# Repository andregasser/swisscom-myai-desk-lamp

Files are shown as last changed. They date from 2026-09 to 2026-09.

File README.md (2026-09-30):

# myAI Cube

Eine kleine Würfellampe zum Selberdrucken: weißes PLA, sanftes Licht und das myAI-Logo mittig auf allen vier Seiten. Entwickelt für den **Bambu Lab P1S** und das **LED Lamp Kit 001 / MH001**.

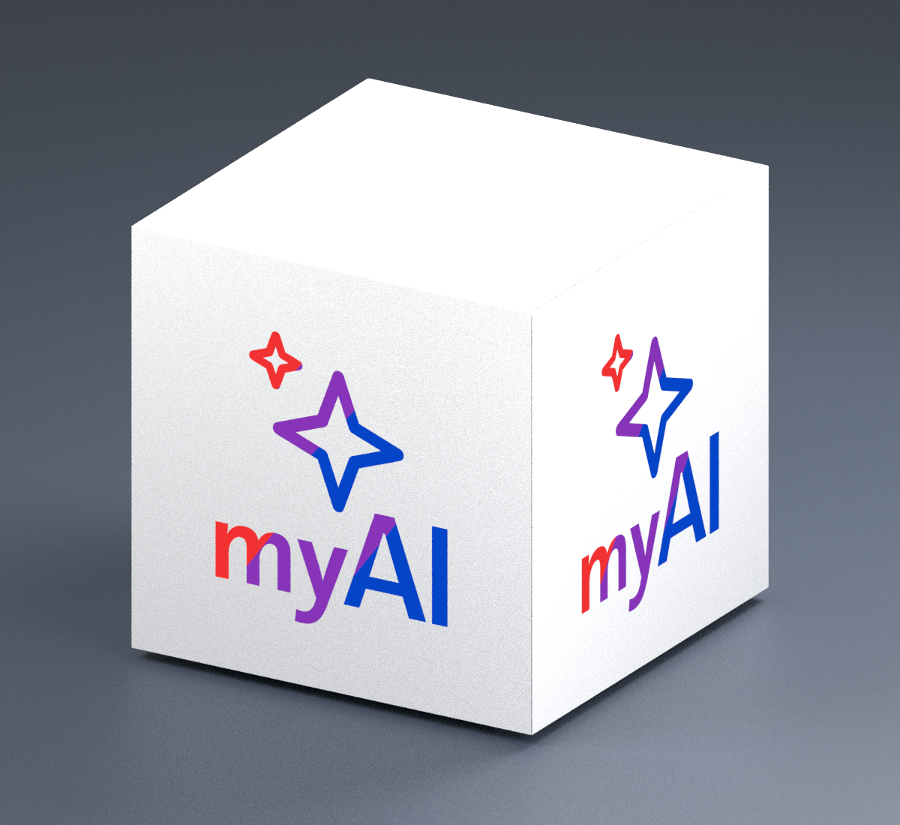
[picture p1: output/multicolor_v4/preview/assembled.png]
myAI Cube v4: durchgehend plane Seiten mit integrierten farbigen Logos


*Technische Farbansicht der CAD-Geometrie: Die Logos zeigen die nominellen sRGB-Farben ohne Aufhellung durch Beleuchtung. Keine Vorhersage realer Filamentfarben oder Lichtwirkung.*

## Die Idee

Ein **15 × 15 × 15 cm** großer Würfel mit **0,8 mm dünnen Leuchtflächen**, integrierten Logos, Boden mit LED-Aufnahme und abnehmbarem Deckel. Für das Logo gibt es eine farbige AMS-Variante und eine einfarbige Alternative.

## Plane Seiten mit AMS — v4

**Vier vollflächige Seitenplatten, außen ohne Vertiefungen oder vorstehende Rahmen.** Die Befestigung liegt innen; nur schmale Montagefugen bleiben an den Würfelkanten. Die 0,8-mm-Leuchtflächen und Logos sind bündig. Innenliegende Führungsleisten erlauben das Einschieben von oben.

**Für ein AMS mit vier Farben:** Weiß, Blau, Violett und Rot. Sterne und Schriftzug „myAI“ folgen Rot → Violett → Blau als feste Farbstufen. Sechs Farbwechsel pro Platte. [Farbvergleich mit den Original-SVGs](output/multicolor_v4/preview/color_reference.png).

Luft und Kabel führen unter dem Boden hindurch. Vier 4-mm-Druckfüße schaffen Abstand; die Gesamthöhe bleibt **150 mm einschließlich Füßen**. Die obere Entlüftung liegt in der 0,8-mm-Deckelfuge auf der Oberseite. Die Füße werden eingesteckt und angeklebt; die Seitenplatten kommen ohne Klebstoff aus.

[Druckdateien & Montage v4](docs/MEHRFARBIG_V4.md) · [Farbprobe](output/multicolor_v4/print/01_color_test_P1S.3mf) · [Führungs-Passprobe](output/multicolor_v4/print/07_fit_P1S.3mf) · [Komplettpaket v4](output/myAI_Cube_150_P1S_AMS_v4.zip)

Sieben vorbereitete P1S-Projekte, keine Stützen. Lampe ohne Proben laut Slicer etwa **267 g PLA und 17 h 22 min**. Zuerst die neue Führung mit der Passprobe prüfen. [Frühere AMS-Variante v3](docs/MEHRFARBIG_V3.md).

**Stand: Prototyp.** Digital geprüft und geslict. Physischer Probedruck und Temperaturtest stehen noch aus.

## Einfarbige Variante v2 drucken

Die ursprüngliche Variante besteht aus Körper, Boden und Deckel. Das innen verstärkte Logo soll sich im Licht dunkler abzeichnen; kein AMS erforderlich. Diese Variante besitzt noch sichtbare Lüftungsöffnungen.

Die 3MF-Projekte sind ausgerichtet und für **P1S · 0,4-mm-Düse · weißes PLA · strukturierte PEI-Platte** vorbereitet. In Bambu Studio **als Projekt** öffnen, eigenes Filament und Druckplatte prüfen und bei Änderungen neu slicen.

| Zuerst testen | Danach die Lampe drucken |
|---|---|
| [Testplatte: Licht und Passung](output/print/01_tests_P1S.3mf) | [Körper](output/print/02_body_P1S.3mf) · [Boden](output/print/03_base_P1S.3mf) · [Deckel](output/print/04_lid_P1S.3mf) |

**Druckprofil:** 0,20-mm-Schichten, keine Stützen. Die Hauptteile benötigen laut Slicer etwa **238 g PLA und 15 h 42 min**. LED-Kit und eine passende 5-V-USB-Stromversorgung kommen dazu.

**Stand: Prototyp v2.** Geometrie und Slicing sind geprüft; ein physischer Probedruck steht noch aus. Deshalb zuerst Lichtdurchlässigkeit und Passung mit der Testplatte prüfen.

## Weiterbauen

- [Druck & Montage](docs/DRUCK_UND_MONTAGE.md) — vom Probedruck zur fertigen Lampe.
- [Projektdetails](docs/PROJEKTDETAILS.md) — Maße, Druckzeiten, Aufbau und Quellen.
- [CAD & Validierung](docs/CAD_UND_VALIDIERUNG.md) — Konstruktion reproduzieren und prüfen.
- [STL-Dateien](output/stl) · [CAD-Parameter](cad/parameters.json) · [Generator](cad/build.py) — für eigene Anpassungen.

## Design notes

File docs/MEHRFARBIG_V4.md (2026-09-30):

# myAI Cube v4 — vier durchgehend plane Seiten

Der Würfel misst **150 × 150 × 150 mm einschließlich Füßen**. Jede Seite besteht aus einer vollflächigen Platte mit bündig integriertem myAI-Logo. Es gibt keine vertieften Logo-Felder, vorstehenden Rahmen oder Deckelblenden an den Seiten. Die Befestigung liegt innen.

V4 mit durchgehend planen Seitenflächen

*Technische Farbansicht der CAD-Geometrie. Logo-Farben werden als nominelle sRGB-Werte dargestellt; keine Vorhersage realer Filamentfarben oder Leuchtwirkung.*

## Aufbau und Oberfläche

- Vier identische Platten: **149,6 × 146 mm**, Leuchtfläche **0,8 mm** stark. Die 0,4-mm-Farbeinlagen liegen bündig in der Vorderseite, dahinter bleiben 0,4 mm Weiß. Die schmalen inneren Führungsleisten erhöhen die lokale Druckhöhe auf 2,8 mm.
- Die Außenflächen liegen auf den Würfelebenen x/y = 0 und 150 mm. Die vertikalen Plattenkanten sind innen auf Gehrung geschnitten, mit 0,2 mm Abstand zur theoretischen Würfelkante. Es bleiben schmale Montagefugen an den vier Kanten; keine eingefassten Felder auf den Seiten.
- Zwei innenliegende, schwalbenschwanzförmige Leisten je Platte gleiten von oben in passende Nuten des inneren Rahmens. Nominell 0,2 mm Spiel um das Führungsprofil; der untere Anschlag trägt die Platte. Der Deckel begrenzt das Anheben. Die Platten werden nicht angeklebt.
- Die Logo-Kontur bleibt auf allen vier montierten Seiten bei **75 / 75 mm** zentriert. Rahmen, Boden und Deckel liegen hinter den Außenflächen.

Die Sichtseite liegt beim Druck auf dem Bett und übernimmt dessen Oberflächenstruktur. „Plan“ bezeichnet hier die Geometrie ohne Absatz; die vorbereitete strukturierte PEI-Platte erzeugt keine polierte Oberfläche. Die Ebenheit großer, dünner PLA-Platten und der Einfluss der inneren Leisten auf die Lichtwirkung müssen am Druck geprüft werden.

## Vier AMS-Farben

| Projekt-Filament | PLA-Farbe | Vorschauwert |
|---|---|---|
| 1 | Weiß | `#FFFFFF` |
| 2 | Blau | `#0445C8` |
| 3 | Violett | `#8734B8` |
| 4 | Rot | `#F23232` |

Sterne und Schrift folgen **Rot → Violett → Blau**. Konturen und Verlaufsrichtungen stammen aus der unveränderten dunklen Original-SVG. Die Farben bleiben gegenüber v3.2.1 erhalten: Rot und Blau sind originale Farbstopps, Violett ist eine gewählte Zwischenfarbe. Das AMS druckt klar getrennte Farbstufen, keinen stufenlosen Verlauf. Eine winzige separate Kontur unterhalb der Düsenauflösung entfällt.

[Direkter Vergleich mit beiden Original-SVGs](../output/multicolor_v4/preview/color_reference.png). Die Druckpalette bildet die zusätzlichen hellblauen/cyanfarbenen Zwischenstufen des Originals nicht exakt ab. Die reale Farbe bestimmt die eingelegte Spule.

## Druckdateien

**[Komplettes Druck- und Quellenpaket v4](../output/myAI_Cube_150_P1S_AMS_v4.zip)**. Im Paket die aktuellen Projekte unter `output/multicolor_v4/print/` verwenden; ältere Varianten liegen separat bei.

Alle Projekte sind für **P1S · 0,4-mm-Düse · PLA · 0,20-mm-Schichten · strukturierte PEI-Platte** ausgerichtet und geslict. Als Projekt in Bambu Studio öffnen und die Projekt-Filamente beim Senden den richtigen AMS-Fächern zuordnen. Bei Änderungen an Filament oder Druckplatte neu slicen. Voreinstellung: Generic PLA, 220 °C Düse und 55 °C Bett.

| Druckprojekt | Anzahl | Zeit je Druck | PLA je Druck¹ |
|---|---:|---:|---:|
| [Farb- und Lichtprobe](../output/multicolor_v4/print/01_color_test_P1S.3mf) | zuerst 1 | 36 min | 7,44 g |
| [Passprobe der inneren Führung](../output/multicolor_v4/print/07_fit_P1S.3mf) | zuerst 1 | 23 min | 2,18 g |
| [Vollflächige Seitenplatte](../output/multicolor_v4/print/02_panel_P1S.3mf) | 4 | 1 h 49 min | 28,34 g |
| [Innerer Rahmen](../output/multicolor_v4/print/03_frame_P1S.3mf) | 1 | 4 h 42 min | 53,70 g |
| [Boden mit LED-Aufnahme](../output/multicolor_v4/print/04_base_P1S.3mf) | 1 | 3 h 38 min | 74,32 g |
| [Deckel](../output/multicolor_v4/print/05_lid_P1S.3mf) | 1 | 1 h 24 min | 22,42 g |
| [Vier Füße auf einer Platte](../output/multicolor_v4/print/06_feet_P1S.3mf) | 1 Satz | 20 min | 3,41 g |

¹ Einschließlich Brim, Spülmaterial und Reinigungsturm, soweit vom Slicer erfasst. Lampe ohne Proben etwa **267 g PLA und 17 h 22 min**. Keine Stützen. Jedes Paneel benötigt sechs Farbwechsel.

1. Zuerst Farbprobe und Passprobe drucken. Die Farbprobe besitzt denselben 0,4 + 0,4-mm-Schichtaufbau, verkleinertes Logo und keine Führungsleisten. Sie beurteilt Farben und Licht, keine Details in Originalgröße.
2. Die Passprobe besteht aus einem 20 mm hohen Ausschnitt des echten Eckpfostens und einem passenden Plattenstreifen mit Führungsleiste, jeweils in der späteren Druckorientierung. Den Streifen aufrichten und die Leiste von oben in eine der beiden Nuten schieben. Die Verbindung soll gleiten, ohne Gewalt oder Aufspreizen des Pfostens. Diese Probe prüft den Querschnitt, noch nicht den Verzug über die volle Führungslänge.
3. Danach zunächst einen Rahmen und eine vollständige Seitenplatte drucken und montieren. Erst nach erfolgreicher Passprobe die übrigen drei Platten drucken. Dünne Platten vom abgekühlten Bett lösen; Brim und lose Fäden sorgfältig entfernen.
4. Die Logo-Vorderseite ist die Bettseite. **Nicht zusätzlich spiegeln oder wenden.** Die vier Farbvolumen bleiben Teile eines gemeinsamen Objekts. Die breitere Platte ist auf dem Bett seitlich versetzt, damit Brim und Reinigungsturm ausreichend Abstand haben.

Der Reinigungsturm ist aktiviert; Fremdfarben werden nicht in die weiße Rückschicht gespült. Vorgesehene Spülmengen: 650 mm³ beim Wechsel auf Weiß, 450 mm³ bei anderen Farbwechseln, anhand des eigenen Filaments prüfen. In den ersten zwei Schichten liegen alle vier Farben, darüber ausschließlich Weiß einschließlich der Führungsleisten. Die CLI-Dateien enthalten Geometrie und G-Code, aber keine integrierten Vorschaubilder.

## Montage und Belüftung

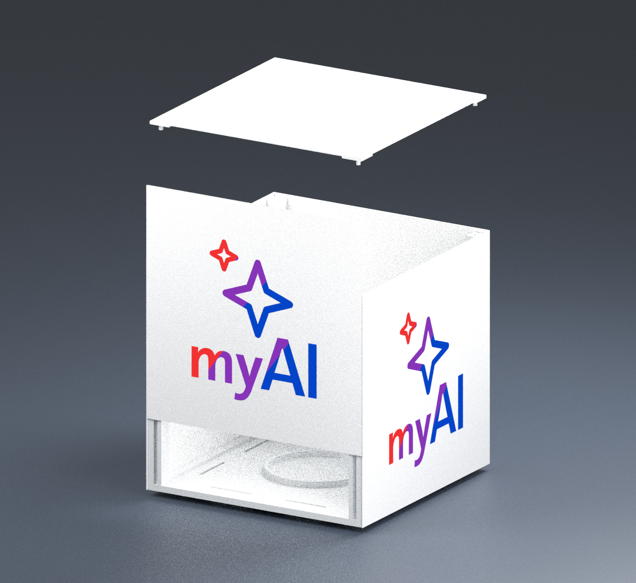
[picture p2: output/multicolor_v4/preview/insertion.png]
Deckel abgenommen und vordere Seitenplatte angehoben


1. Vier Füße in die Aufnahmen auf der Bodenunterseite stecken und mit wenig PLA-geeignetem Klebstoff fixieren. Die 4-mm-Pads flach anlegen. Zapfen Ø 4,0 × 1,8 mm, Aufnahmen Ø 4,4 × 2,0 mm: bewusst eine lose Passung.
2. LED Lamp Kit 001/MH001 in die nominell 60-mm-Aufnahme setzen und mit dem Kit-Klebepad befestigen. Die Konstruktion verwendet ein nominell 59-mm-Modul; das konkrete Kit prüfen. Seine Auflage liegt 7 mm über der Stellfläche.
3. Kabel durch den nach hinten offenen, 6 mm breiten Bodenschlitz nach unten legen. Es verlässt die Lampe **unter** der hinteren Seitenplatte. Die Füße schaffen dafür 4 mm Bodenfreiheit. Den tatsächlichen Kabeldurchmesser und einen knickfreien Verlauf prüfen; kein Stecker muss durch eine geschlossene Bohrung gefädelt werden.
4. Rahmen auf die vier Führungsstifte des Bodens setzen. Vier Seitenplatten mit aufrechter Schrift und Bettseite nach außen von oben einschieben, bis die inneren Leisten auf den Anschlägen sitzen. Der Rahmen darf nicht gewaltsam gespreizt werden.
5. Deckel in die vier oberen Aufnahmen setzen. Zum Öffnen an der oberen Deckelfuge vorsichtig abheben. Boden und Deckel stecken lose; beim Tragen den Boden unterstützen.

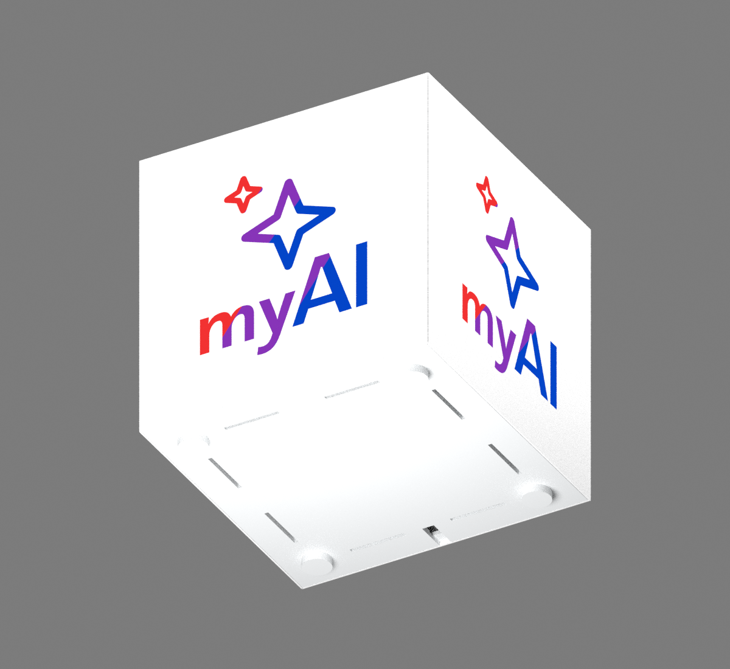
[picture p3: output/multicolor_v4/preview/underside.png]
Unterseite mit Einlässen, Füßen und Kabelschlitz


Die Belüftung ist an die planen Seiten angepasst:

- **Einlass unten:** Acht Bodenschlitze à 28 × 2 mm, zusammen nominell 448 mm². Auf einer harten, ebenen Fläche bleiben sie durch die 4-mm-Füße offen.
- **Auslass oben:** Vier unterseitige Deckelkanäle à 120 × 1,2 mm führen in die **0,8 mm breite Montagefuge zwischen Deckel und Seitenplatten auf der Oberseite**. Dort beträgt der nominelle Austrittsquerschnitt über den vier Kanalabschnitten 384 mm². Diese schmale obere Fuge bleibt sichtbar und offen; die eigentliche Deckelfläche ist geschlossen. Es gibt keine vertieften Auslässe auf den Seiten.

Die Luftwege sind im montierten CAD frei und zusammenhängend. Das ist kein Nachweis ausreichender Kühlung. Temperatur an LED-Aufnahme, Boden und Deckel im beaufsichtigten Betrieb bis zum stabilen Zustand prüfen. Passung, Verzug, Lichtverteilung und Dauerbetrieb sind noch nicht physisch bestätigt.

**V4 als vollständigen neuen Teilesatz verwenden.** Die früheren Paneele, Rahmen, Böden, Deckel und Füße sind hierfür nicht vorgesehen. Die alten v3-Dateien und Versionspakete bleiben im Repository erhalten.

## Reproduzieren und prüfen

Quellen: [AMS-Parameter](../cad/multicolor_parameters.json), [Generator](../cad/build_multicolor.py). Grundfunktionen und LED-Ring werden aus `cad/build.py` importiert. `output_folder` wählt das aktuelle Ausgabeverzeichnis. Allgemeine Umgebung: [CAD & Validierung](CAD_UND_VALIDIERUNG.md).

```sh
.venv/bin/python cad/build_multicolor.py
.venv/bin/python scripts/prepare_profiles.py /pfad/zu/BambuStudio/resources/profiles/BBL
.venv/bin/python scripts/slice_multicolor.py /pfad/zu/bambu-studio
.venv/bin/python scripts/validate_multicolor.py
blender -b -t 4 --python scripts/render_multicolor.py
.venv/bin/python scripts/render_color_reference.py
.venv/bin/python scripts/validate_colors.py
.venv/bin/python scripts/package.py
```

Verwendeter Slicer: Bambu Studio 2.8.2.61. Die Prüfungen stehen in [Geometrie](../output/multicolor_v4/geometry_validation.json), [Druckdateien](../output/multicolor_v4/print_validation.json) und [Farben](../output/multicolor_v4/color_validation.json):

- Geschlossene Materialvolumen, vollständige Abdeckung der Platte einschließlich Leisten, keine relevanten Materialüberschneidungen, kollisionsfreie Montage und Einschubbewegung. Seitliches Herausziehen wird durch die Führungsgeometrie blockiert.
- Außenmaß 150³ mm, Logo-Zentrierung 75/75 mm und durchgehende ebene Außenhaut auf allen vier Seiten, mit Ausnahme der vorgesehenen schmalen Kantenfugen. Freie Luft- und Kabelwege. Die Boolesche Volumentoleranz beträgt 0,001 mm³.
- Sieben geslicte P1S-Projekte, korrekte AMS-Zuordnung, gültige G-Code-Prüfsummen, Bettgrenzen einschließlich Brim/Reinigungsturm, keine Stützen oder Slicer-Druckwarnungen.
- Nominelle RGB-Farben in den technischen Vorschauen; kein gemessener Farb- oder Helligkeitsnachweis am gedruckten Material.

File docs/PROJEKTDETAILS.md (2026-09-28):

# Projektdetails — myAI Cube

3D-druckbare Würfellampe aus weißem PLA für das **Bambu Lab LED Lamp Kit 001 / MH001 (nominal Ø 59 mm)**. Vier gleiche Logo-Seiten, separate Bodenplatte, abnehmbarer Deckel. Zusammengesetzt **150 × 150 × 150 mm**.

**Version 2:** Die tatsächliche Logo-Kontur ist auf jeder montierten 150-mm-Seite geometrisch zentriert (Mitte bei 75 / 75 mm). Die Zentrierung berücksichtigt die leeren SVG-Ränder, Boden-/Deckelhöhe und die Neigung des inneren Reliefs. Das Logo bleibt ein integrierter Teil des weißen Drucks.

## Direkt zum Druck

Die fertig ausgerichteten, mit **Bambu Studio 2.8.2.61** geslicten P1S-Projekte liegen in [output/print](../output/print). Jede Datei enthält eine Druckplatte, das Modell, die Einstellungen und den erzeugten G-Code.

| Reihenfolge | Projekt | Inhalt | PLA, ca. | Zeit, ca. |
|---|---|---|---:|---:|
| 1 | [01_tests_P1S.3mf](../output/print/01_tests_P1S.3mf) | Vier Lichtproben, LED-Passring, zwei Steckproben | 28 g | 1 h 56 min |
| 2 | [02_body_P1S.3mf](../output/print/02_body_P1S.3mf) | Vierseitiger Lampenkörper, 145 mm hoch | 116 g | 9 h 19 min |
| 3 | [03_base_P1S.3mf](../output/print/03_base_P1S.3mf) | Boden, 3 mm plus innenliegende Aufnahmen | 89 g | 4 h 14 min |
| 4 | [04_lid_P1S.3mf](../output/print/04_lid_P1S.3mf) | Deckel, außen bündig; Führung innen | 34 g | 2 h 9 min |

**Profil:** P1S, 0,4-mm-Düse, weißes Generic PLA, strukturierte PEI-Platte, 0,20-mm-Schichten, Arachne, zwei Wände, 100 % Füllung, keine Stützen, 4-mm-Außenbrim. Das eingebettete Filamentprofil verwendet 220 °C Düse und 55 °C Bett. Keine AMS-Farbwechsel.

1. `01_tests_P1S.3mf` in Bambu Studio **als Projekt** öffnen und im Maßstab 100 % belassen.
2. P1S mit 0,4-mm-Düse, die tatsächlich verwendete Druckplatte und dein weißes PLA auswählen. Wenn du ein anderes Filament- oder Plattenprofil verwendest, erneut slicen. Die Ausrichtung beibehalten.
3. Testplatte drucken. [Passung und Licht prüfen](DRUCK_UND_MONTAGE.md), danach die drei Hauptplatten drucken.

Die Lampe selbst benötigt etwa **238 g PLA / 15 h 42 min**. Die Angaben sind Slicer-Schätzungen inklusive Brim; tatsächliche Werte können abweichen. Die Konstruktion wurde digital geprüft und geslict, **noch nicht physisch probegedruckt**.

## Konstruktion

- Leuchtflächen und Deckelmitte: 0,8 mm. Randbereiche: 3 mm am Körper, 2 mm am Deckel. Verstärkte Ecken.
- Vollständiges gestapeltes myAI-Logo auf allen vier Seiten. Einfarbiges Relief **innen**, außen ebene Flächen. Das Logo ist mit insgesamt etwa 1,6 mm Material dicker und soll bei Beleuchtung dunkler erscheinen; Farbverläufe sind nicht Bestandteil des Drucks.
- LED-Aufnahme: Ø 60,0 mm innen, 4 mm hoch, mit Kabelschlitz. Die mitgelieferte Ø-40-mm-Klebescheibe fixiert das Kit am Boden. Die Führung ist keine Klemm- oder Schraubverbindung.
- 0,35 mm Spiel je Seite an den Führungsleisten. Körper und Deckel sitzen lose auf; sie sind abnehmbar und verriegeln nicht.
- Kabelauslass hinten, unten offen, 6 mm breit. Vier kleine Lüftungsöffnungen pro Seitenwand und vier Schlitze im Deckel.

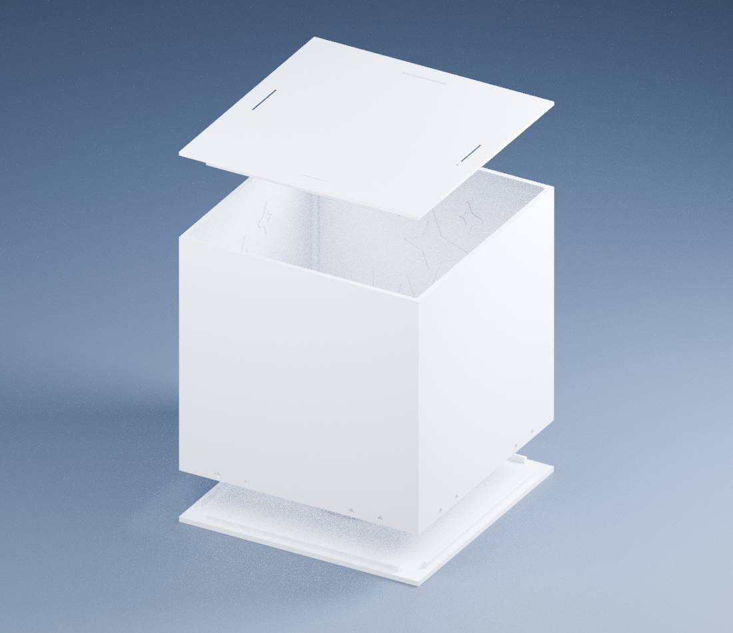
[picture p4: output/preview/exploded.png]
Montageansicht


Ansicht aus den tatsächlichen Druckmeshes. Die zusätzliche [Beleuchtungsansicht](../output/preview/assembled.png) ist eine schematische Materialsimulation, keine Vorhersage der Helligkeit oder des Logokontrasts.

## Dateien und Änderungen

- [STL-Einzelteile](../output/stl): Millimeter, bereits in Druckorientierung.
- [CAD-Parameter](../cad/parameters.json) und [Generator](../cad/build.py): reproduzierbare Geometrie.
- [Druck- und Montageanleitung](DRUCK_UND_MONTAGE.md).
- [Geometrieprüfung](../output/validation.json) und [Druckdateiprüfung](../output/print_validation.json).
- [Original-Logos](../assets/logos): unverändert. Für den Druck wird die Kontur der Light-Variante benutzt; ein winziges, nicht druckbares SVG-Dreiecksfragment wird beim Ableiten entfernt.

```sh
python3 -m venv .venv
.venv/bin/pip install -r cad/requirements.txt
.venv/bin/python cad/build.py
```

Nach Parameteränderungen sind die vorhandenen P1S-Druckprojekte veraltet: die neuen Geometrie-3MFs in `output/3mf` erneut slicen. Die Geometrieprüfungen laufen beim Erzeugen automatisch. Für die CLI-Reproduktion siehe [CAD und Validierung](CAD_UND_VALIDIERUNG.md).

## Quellen

- [Bambu LED Lamp Kit 001: Herstellerdaten](https://asia.store.bambulab.com/products/led-lamp-kit-001?modelId=126239&skr=yes): nominal Ø 59 mm, USB 5 V, 3 W. Die Aufnahme hält nur den unteren Rand; sie setzt keine bestimmte Gesamthöhe des Kits voraus.
- [Bambu 3D Printing Night Light Design Guidelines, PDF-Spiegel](https://www.eel3dshop.com/shop_ordered/54291/pic/Datasheet/BambuLab/LED_Lamp_Kit-001_Design_Guide.pdf): 0,8-mm-Lampenschirm und Belüftung als Konstruktionsgrundlage.
- [Bambu Studio 2.8.2.61](https://github.com/bambulab/BambuStudio/releases/tag/v02.08.02.61): offizieller Slicer und mitgelieferte P1S-/PLA-Profile.

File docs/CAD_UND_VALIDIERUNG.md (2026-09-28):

# Reproduzierbarkeit und Prüfstand

## Geometrie

`cad/build.py` erzeugt die Geometrie mit Manifold3D. Die SVG-Kontur wird aus dem unveränderten Light-Logo abgeleitet und als Relief mit der Wand vereinigt. Kurven werden mit höchstens etwa 0,2 mm Abtastabstand polygonisiert. Das separate Dreiecksfragment am A mit weniger als 0,02 mm² wird beim Ableiten ausgelassen, um einen nicht druckbaren Punktkontakt zu vermeiden.

Das Logo wird nach innen und gleichzeitig nach oben extrudiert. Die dadurch geneigten Unterkanten reduzieren freie Überhänge beim aufrechten Druck. Die äußeren Seitenflächen bleiben eben. Die Farbdaten beider Original-SVGs bleiben in `assets/logos` erhalten, werden aber nicht als Druckfarben übernommen.

Ab Version 2 wird die Begrenzungsbox der zusätzlichen Logo-Materialstärke auf die Mitte der zusammengesetzten Seite gesetzt, statt die SVG-Zeichenfläche zu zentrieren. Eine numerische Prüfung bestätigt 75 / 75 mm für die projizierte Kontur. Alle vier Seiten verwenden dieselbe Geometrie, jeweils um 90° gedreht.

Für Änderungen zuerst die Parameter anpassen und dann:

```sh
.venv/bin/python cad/build.py
```

Der Generator prüft geschlossene, zusammenhängende Volumenkörper, positive Volumina, Druckbettkontakt und Teilegrößen. Er prüft die zusammengesetzte Lampe auf paarweise Materialüberschneidungen. Ein nominaler Ø-59-mm-Zylinder als vereinfachter LED-Platzhalter kollidiert nicht mit der Aufnahme. Diese Prüfung ersetzt nicht das reale Kit samt Kabel und Fertigungstoleranzen.

## Bambu Studio

Die mitgelieferten Druckdateien wurden mit **Bambu Studio 02.08.02.61** und dessen offiziellen Ressourcen erzeugt. `scripts/prepare_profiles.py` löst die Vererbung einschließlich der originalen P1S-Start-/End-G-Code-Vorlagen auf. `output/profiles` enthält die konkret verwendeten Profile. Die Druckparameter sind in jedem fertigen 3MF eingebettet.

```sh
.venv/bin/python scripts/prepare_profiles.py /pfad/zu/BambuStudio/resources/profiles/BBL
.venv/bin/python scripts/slice.py /pfad/zu/bambu-studio
.venv/bin/python scripts/validate_prints.py
```

Die Linux-AppImage wurde für die Erstellung nur unter `/tmp` entpackt. Fehlende Laufzeitbibliotheken wurden ebenfalls dort bereitgestellt; sie gehören nicht zum Druckpaket. Zum Öffnen und Drucken genügt eine reguläre Bambu-Studio-Installation, empfohlen 2.8.2 oder neuer.

## Tatsächlich geprüft

- Alle zehn STL-Einzelteile erneut eingelesen: geschlossene, konsistent orientierte, zusammenhängende Körper.
- Zusammengebautes Außenmaß: 150 × 150 × 150 mm. Keine Überschneidung von Boden, Körper und Deckel.
- Vier Platten erfolgreich geslict; in den Slicer-Ergebnisdaten keine Druckwarnungen.
- Eingebettetes Profil: P1S / 0,4 mm / PLA / strukturierte PEI-Platte / 0,20 mm / keine Stützen.
- Die erzeugten Modell- und Brim-Extrusionskoordinaten liegen auf dem nutzbaren Bett und außerhalb des vorderen linken Ausschlussbereichs. Offizielle Start-/Reinigungsbewegungen werden davon getrennt behandelt.
- ZIP-Integrität der 3MFs und eingebettete MD5-Prüfsumme jedes G-Codes geprüft. SHA-256-Prüfsummen stehen in `output/print_validation.json`.

Die CLI kann in dieser Umgebung keine OpenGL-Plattenvorschaubilder erzeugen; sie meldet dafür einen Display-Fehler, exportiert aber erfolgreich Geometrie, Profile und geslicten G-Code. Die Projekte enthalten deshalb keine eingebetteten Platten-Thumbnails. Bambu Studio kann die Modelle beim Öffnen selbst anzeigen. Separate Modellansichten liegen unter `output/preview`.

**Nicht physisch geprüft:** Sitz am konkreten LED-Kit, Drucktoleranzen, Verzug, langfristige Wärmebeständigkeit, Leuchtdichte und Logo-Kontrast. Dafür liegt die Testplatte bei. Die Renderansichten zeigen die Geometrie; Material und Beleuchtung sind illustrativ.

## Vorschauen

`output/preview/assembly.glb` enthält die tatsächlichen drei montierten Druckmeshes und ist nicht als Druckplatte gedacht. `scripts/render.py` erzeugt mit Blender 5 die PNG-Ansichten aus den STL-Dateien:

```sh
blender -b -t 4 --python scripts/render.py
```

Die originalen P1S-/PLA-Grundprofile stammen aus [Bambu Studio](https://github.com/bambulab/BambuStudio/tree/v02.08.02.61/resources/profiles/BBL). Die Befehlszeile folgt der [offiziellen CLI-Dokumentation](https://github.com/bambulab/BambuStudio/wiki/Command-Line-Usage).

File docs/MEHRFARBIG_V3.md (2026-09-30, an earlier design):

# myAI Cube v3.2.1 — Logo direkt mit dem AMS drucken

> Archivierter Entwurf mit zurückgesetzten Seitenfeldern. Der aktuelle Entwurf mit planen Seiten ist [v4](MEHRFARBIG_V4.md). Die folgenden Reproduktionsbefehle gelten für die Quellen im v3.2.1-Archiv; die aktuellen Quellen im Repository erzeugen v4.

Der Würfel bleibt **150 × 150 × 150 mm einschließlich Füßen** groß. Vier identische, flach gedruckte Leuchtpaneele werden von oben in einen weißen Rahmen eingeschoben. Das mehrfarbige Logo ist bündig in jedes Paneel integriert. Der abnehmbare Deckel schließt die Führungen. Die Logos benötigen keinen Klebstoff.

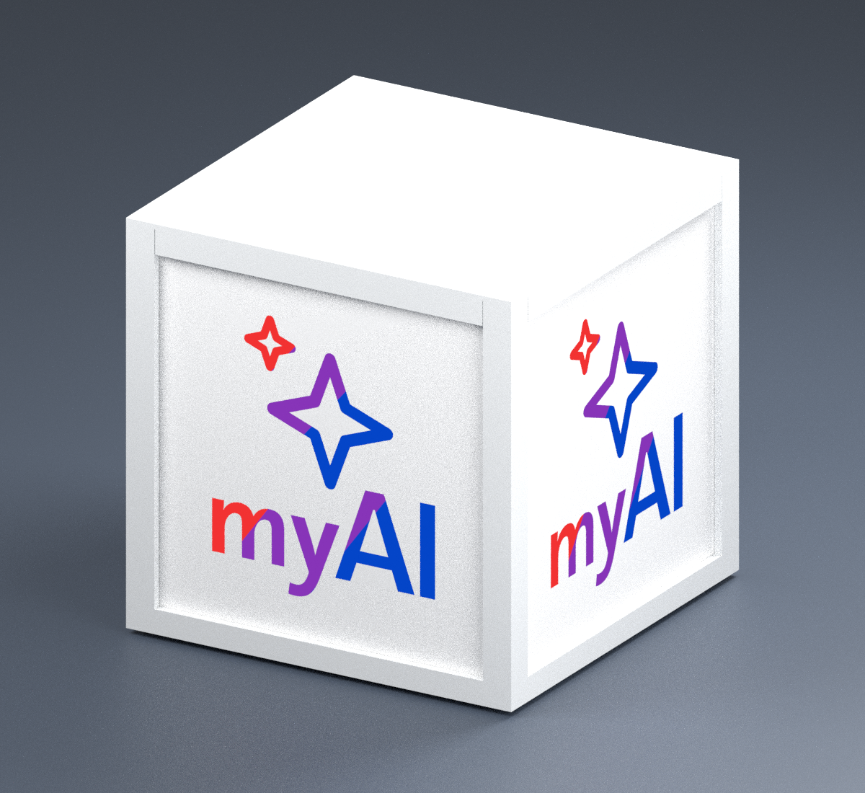
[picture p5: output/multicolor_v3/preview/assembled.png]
Zusammengesetzter AMS-Entwurf


*Technische Farbansicht der tatsächlichen CAD-Geometrie. Die Logo-Flächen zeigen nominelle sRGB-Farben ohne Aufhellung durch Szenenbeleuchtung. Keine Vorhersage der Leuchtwirkung oder realer Filamentfarben.*

## Vier Farben in einem AMS

| Projekt-Filament | PLA-Farbe | Verwendung |
|---|---|---|
| 1 | Weiß | Paneel, Rückschicht, Rahmen, Boden, Deckel, Füße |
| 2 | Blau | Blaue Bereiche in Sternen und Schrift |
| 3 | Violett | Mittlere Farbstufe in Sternen und Schrift |
| 4 | Rot | Rote Bereiche in Sternen und Schrift |

Die Konturen stammen jetzt aus der unveränderten **dunklen Logo-SVG**: Sie enthält Farbverläufe sowohl in den Sternen als auch in „myAI“. Die zuvor verwendete helle SVG besitzt einfarbig dunkelblaue Schrift. Beide Originaldateien bleiben unverändert.

Die gewünschte Druckfolge ist **Rot → Violett → Blau**. Sterne und Schrift behalten ihre jeweils eigene Verlaufsrichtung aus der SVG; der Generator liest die Gradientenzuordnung jedes Pfads. Die Farbpalette wird für diesen Entwurf bewusst angepasst: Weiß `#FFFFFF`, Blau `#0445C8`, Violett `#8734B8`, Rot `#F23232`. Die Original-SVG enthält zusätzlich hellblaue/cyanfarbene Zwischenstufen, die hier durch die gewünschte dreistufige Folge ersetzt werden. Die Hexwerte dienen der Vorschau und sind keine gemessenen Filamentfarben.

Es ist eine **druckbare Vierfarben-Annäherung mit sichtbaren Farbkanten**, kein stufenloser Verlauf. Entlang jedes originalen Gradientenvektors wird bis t = 0,18 Rot, von t = 0,18 bis 0,50 Violett und danach Blau verwendet; auch innerhalb einzelner Buchstaben entstehen Farbwechsel. Diese Grenzen stehen in `gradient_band_edges` in den CAD-Parametern. Eine winzige separate Kontur unterhalb der Düsenauflösung entfällt wie bei den bisherigen Versionen.

### Farbvergleich und Vorschaukorrektur v3.2.1

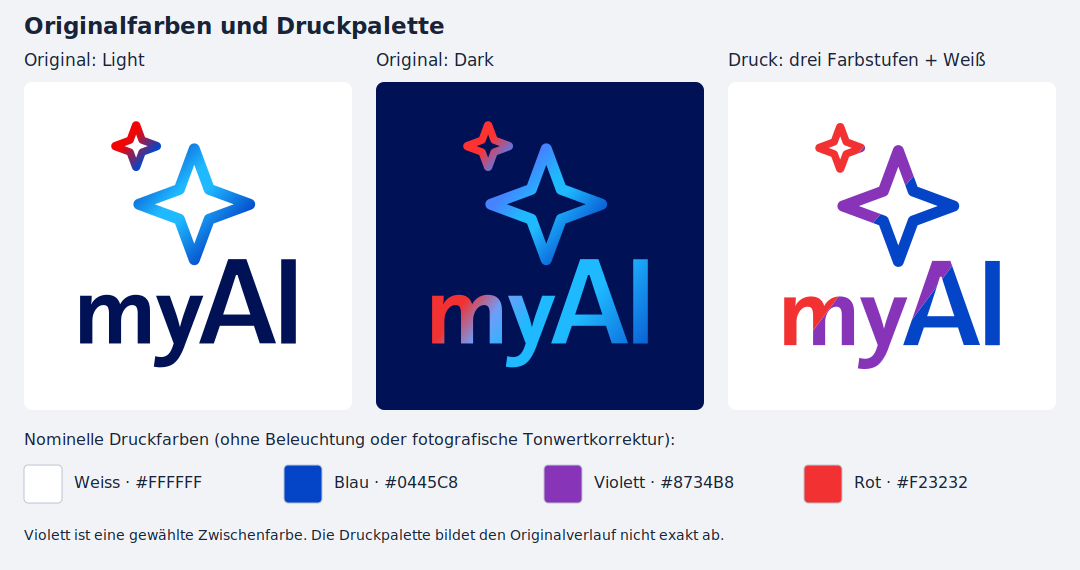
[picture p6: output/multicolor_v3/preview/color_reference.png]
Originale Light/Dark und unbeleuchtete Druckpalette im direkten Vergleich


Die vorherige 3D-Vorschau hellte die Farben durch Beleuchtung und fotografische Tonwertkorrektur stark auf. Rot `#F23232` und Blau `#0445C8` entsprechen bereits Farbstopps der dunklen Original-SVG; diese Werte bleiben erhalten. Violett `#8734B8` ist eine gewählte Zwischenfarbe, kein eigener Farbstopp in der Originaldatei.

Die neue technische Ansicht gibt die Logo-Farben direkt zur Kamera aus, ohne Beleuchtungsaufhellung und mit Standard-sRGB-Ausgabe. Weiße Gehäuseteile bleiben schattiert. Die farbigen Flächen sind dadurch **keine Simulation leuchtenden Filaments**. Der [Farbprüfbericht](../output/multicolor_v3/color_validation.json) prüft die Farbfelder der Vergleichsgrafik und große Innenflächen der gerenderten Logos gegen die CAD-Farbwerte.

**V3.2.1 ändert nur Darstellung, Prüfungen und Dokumentation.** Geometrie, Filamentprofile und geslicte Druckdateien sind identisch zu v3.2; kein erneuter Druck wegen dieser Vorschaukorrektur nötig. Wie dunkel die reale Lampe erscheint, hängt vom tatsächlich eingelegten Filament und der Beleuchtung ab. Hexwerte im Projekt ändern die Farbe einer realen Spule nicht.

Die Paneele sind **133,4 × 139,4 × 0,8 mm** groß. Außen liegen 0,4 mm tiefe Farbeinlagen und weißer Hintergrund, dahinter eine durchgehende 0,4-mm-Schicht aus Weiß. Das Logo ist auf jeder montierten Würfelseite bei **75 / 75 mm** zentriert. Farbflächen dämpfen das Licht anders als weißes PLA; Farbe und Kontrast müssen mit dem eigenen Filament geprüft werden.

## Druckdateien

Alle Links führen zu geslicten **Bambu-Studio-Projekten** für P1S, 0,4-mm-Düse, 0,20-mm-Schichten und strukturierte PEI-Platte. Ein Paneel pro Druckplatte; viermal unverändert drucken.

| Druckprojekt | Anzahl | Slicer-Zeit je Druck | PLA je Druck¹ |
|---|---:|---:|---:|
| [Farb- und Lichtprobe](../output/multicolor_v3/print/01_color_test_P1S.3mf) | zuerst 1 | 34 min | 7,05 g |
| [Seitenpaneel mit Logo](../output/multicolor_v3/print/02_panel_P1S.3mf) | 4 | 91 min | 23,24 g |
| [Rahmen](../output/multicolor_v3/print/03_frame_P1S.3mf) | 1 | 5 h 52 min | 69,56 g |
| [Boden / LED-Aufnahme](../output/multicolor_v3/print/04_base_P1S.3mf) | 1 | 3 h 51 min | 76,27 g |
| [Deckel](../output/multicolor_v3/print/05_lid_P1S.3mf) | 1 | 2 h | 31,66 g |
| [Vier Füße auf einer Platte](../output/multicolor_v3/print/06_feet_P1S.3mf) | 1 Satz | 15 min | 1,90 g |

¹ Einschließlich Brim, Spülmaterial und Reinigungsturm, soweit vom Slicer erfasst. Lampe ohne Testprobe insgesamt etwa **272 g PLA und 18 h 2 min**. Es werden keine Stützen erzeugt. Jedes Paneel benötigt sechs Farbwechsel. Der Boden druckt mit der flachen Unterseite auf dem Bett; lediglich die kleinen, 4,4 mm breiten Fußaufnahmen werden oben überbrückt. Die Füße drucken mit dem runden Pad auf dem Bett und dem Zapfen nach oben.

**[Komplettes Druck- und Quellenpaket v3.2.1 herunterladen](../output/myAI_Cube_150_P1S_AMS_v3_2_1.zip)**. Das Paket enthält zusätzlich die bisherige einfarbige v2; für diesen Entwurf die Dateien unter `output/multicolor_v3/print/` verwenden. Die älteren v3-, v3.1- und v3.2-Pakete bleiben als Archive erhalten.

1. Die Farbprobe **als Projekt** öffnen. Die vier Projekt-Filamente beim Senden den passenden realen AMS-Fächern zuordnen; die Datei kennt deine geladenen Spulen nicht. Für die weißen Druckprojekte Projekt-Filament 1 dem weißen Fach zuweisen.
2. Eigenes PLA und Druckplatte prüfen. Voreinstellung: Generic PLA, 220 °C Düse, 55 °C Bett. Bei Profil- oder Materialänderungen neu slicen und die Vorschau prüfen.
3. Die Logo-Vorderseite liegt auf dem Druckbett. Im Blick von oben erscheint die Rückseite entsprechend gespiegelt. **Nicht zusätzlich spiegeln oder wenden.** Alle vier Farbvolumen bleiben Teile eines gemeinsamen Objekts.
4. Zuerst die kleine Probe drucken und vor dem LED-Kit prüfen. Sie hat denselben Schichtaufbau, aber nur 35 % der Logo-Größe; sie dient dem Farb-/Lichtvergleich, nicht der Beurteilung feiner Details in Originalgröße oder der mechanischen Passung.
5. Danach einen Rahmen und zunächst ein vollständiges Paneel drucken. Brim sauber entfernen und den Sitz prüfen, bevor die drei übrigen Paneele gedruckt werden. Dünne Paneele erst vom abgekühlten Bett lösen und nicht stark knicken.

Der Reinigungsturm ist aktiviert. Spülen in die Leuchtflächen ist deaktiviert, damit Restfarben nicht in der weißen Rückschicht landen. Vorgesehen sind konservative Spülmengen von 650 mm³ beim Wechsel auf Weiß und 450 mm³ bei anderen Farbwechseln; anhand der Probe für das eigene Filament bewerten. Die kleinen Vorschaubilder innerhalb der 3MF-Dateien fehlen wegen des kopflosen CLI-Exports; die Geometrie und der geslicte G-Code sind enthalten.

## Verdeckte Belüftung

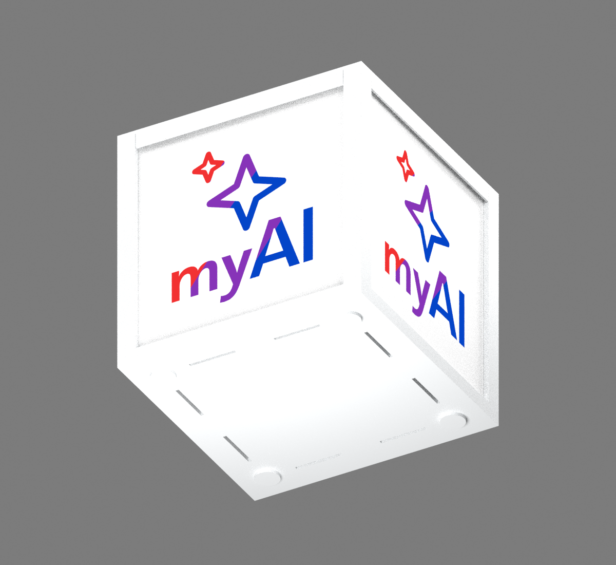
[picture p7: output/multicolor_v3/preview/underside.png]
Unterseite mit acht Lufteinlässen und vier kleinen Füßen


Die Seitenlöcher und die Schlitze auf der Deckelfläche entfallen. Die hintere Kabelöffnung bleibt erhalten.

- **Unten:** Vier separate Druckfüße mit 14 mm Durchmesser schaffen 2 mm Bodenfreiheit. Acht Schlitze à 28 × 2 mm liegen auf der Unterseite. Ihre gesamte nominelle Öffnungsfläche beträgt 448 mm². Der Boden ist nach innen versetzt: Der äußere Auflagerand ist 1 mm stark, die zentrale Platte 3 mm. So bleiben Außenmaße, Paneele und Logo-Position unverändert.
- **Oben:** Vier 100 mm breite und 1,2 mm hohe Kanäle liegen auf der Unterseite des Deckelrandes. Von dort führt die Luft hinter der 1,2 mm starken äußeren Blende nach unten ins Freie. Der Abstand zwischen Blende und Paneel beträgt 2,05 mm. Die Deckelfläche bleibt durchgehend 0,8 mm stark; keine Öffnungen von oben. Die Kanalquerschnitte ergeben zusammen nominell 480 mm².

Das CAD prüft zusammenhängende freie Luftwege vom Raum unter der Lampe bis zum Innenraum und vom Innenraum zu den verdeckten oberen Auslässen. **Das ist keine Strömungs- oder Wärmeberechnung.** Die Umlenkung am Deckel erzeugt einen Strömungswiderstand; die angegebenen Flächen belegen keine ausreichende Kühlleistung. Die Lampe auf eine harte, ebene Fläche stellen, damit die unteren Einlässe frei bleiben.

## Montage

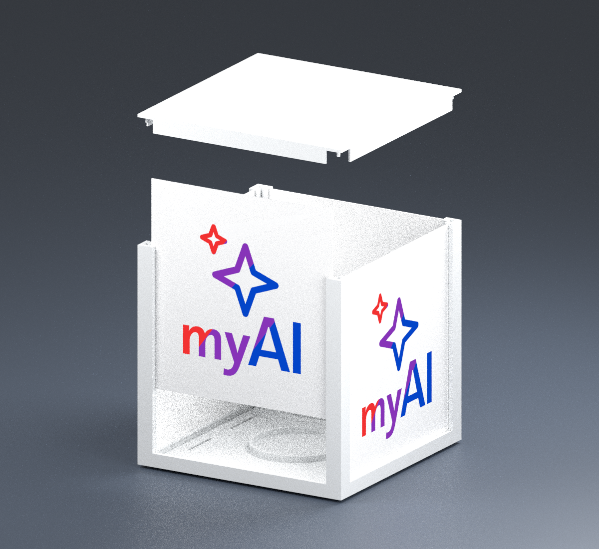
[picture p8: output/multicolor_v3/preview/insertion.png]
Deckel abgenommen, vorderes Paneel teilweise eingeschoben


1. Vier Füße in die runden Aufnahmen auf der Bodenunterseite stecken. Zapfen Ø 4,0 × 1,8 mm, Aufnahme Ø 4,4 × 2,0 mm: bewusst eine lose Passung. Mit wenig PLA-geeignetem Klebstoff fixieren; keine Lüftungsschlitze verschließen. Die 2 mm hohen Pads müssen flach anliegen. Für diesen Schritt ist zusätzlicher Klebstoff erforderlich.
2. LED Lamp Kit 001/MH001 in die nominell 60-mm-Aufnahme des Bodens setzen und mit dem vorgesehenen Klebepad befestigen. Die Auslegung basiert auf einem nominell 59-mm-Modul; tatsächliches Kit vor Montage prüfen. Die LED-Auflage liegt jetzt 5 mm über der Stellfläche. Kabel durch die offene Aussparung führen und den Verlauf zur hinteren Öffnung prüfen.
3. Rahmen auf den Boden setzen, die hintere Kabelöffnung ausrichten. Die Verbindung steckt lose auf dem Boden; kein verriegelter Transportgriff.
4. Vier Paneele von oben in die Führungen schieben, bedruckte Bettseite nach außen und Schrift aufrecht. Seitlich sind nominal 0,3 mm Spiel je Kante vorgesehen; durch die Dicke ergibt sich 0,25 mm vorne und 0,35 mm hinten. Paneele nicht gewaltsam einschieben.
5. Deckel aufsetzen. Seine seitlichen Blenden schließen die oberen Fenster und halten die Paneele in den Führungen. Den Luftspalt hinter der Blende frei lassen. Beim Tragen den Boden unterstützen.

**Rahmen, Boden, Deckel und Füße aus v3.1 passen unverändert zu v3.2.** Neu sind die Farbprobe und die Logo-Paneele mit der geänderten Farbaufteilung; ihre Außenmaße und Passungen bleiben gleich. Für die neuen Farben müssen die Paneele neu gedruckt werden. Der frühere geschlossene Boden aus v2/v3 hat keine Lufteinlässe und ist dafür ungeeignet. Den ersten Betrieb beaufsichtigen und die Temperatur an LED-Aufnahme, Boden und Deckel über einen längeren Betrieb bis zum stabilen Zustand prüfen. Wärmeverhalten und Passung sind noch nicht praktisch bestätigt.

## Quellen und digitale Prüfung

Maße/Farben: [Parameter](../cad/multicolor_parameters.json). Konturen, Rahmen, Boden, Füße und Montage: [Generator](../cad/build_multicolor.py). Die Original-SVGs bleiben unverändert. Die Ringgeometrie der LED-Aufnahme und Grundfunktionen werden aus dem v2-Generator importiert.

```sh
.venv/bin/python cad/build_multicolor.py
.venv/bin/python scripts/prepare_profiles.py /pfad/zu/BambuStudio/resources/profiles/BBL
.venv/bin/python scripts/slice_multicolor.py /pfad/zu/bambu-studio
.venv/bin/python scripts/validate_multicolor.py
blender -b -t 4 --python scripts/render_multicolor.py
.venv/bin/python scripts/render_color_reference.py
.venv/bin/python scripts/validate_colors.py
.venv/bin/python scripts/package.py
```

Python-Abhängigkeiten und Bambu-Studio-Einrichtung: [CAD & Validierung](CAD_UND_VALIDIERUNG.md). Verwendet: Bambu Studio 2.8.2.61. Der Slicer erzeugt zuerst eine native Mehrteil-Projektdatei; anschließend werden die vier Teile explizit den Filamenten zugeordnet und regulär geslict. G-Code wird nicht nachbearbeitet.

- [Geometrieprüfung](../output/multicolor_v3/geometry_validation.json): geschlossene Materialvolumen, vollständige Paneelabdeckung, keine relevanten Volumenüberschneidungen, kollisionsfreie Montage und Einschubbewegung, Außenmaße einschließlich Füßen und Logo-Zentrierung. Zusätzlich: alle drei Druckfarben auch im Schriftbereich, freie verbundene Luftwege, geschlossene Deckelfläche und geschlossene frühere Seitenöffnungen. Getrennte Buchstaben/Sternflächen sind absichtlich mehrere Inseln eines Materialteils; die Füße sind vier getrennte Körper auf einer Druckplatte. Boolesche Abweichungen an gemeinsamen Grenzflächen werden mit 0,001 mm³ Toleranz bewertet.
- [Druckprüfung](../output/multicolor_v3/print_validation.json): geschlossene exportierte STL-Netze, vier korrekte Materialzuordnungen ohne Slicer-Netzreparatur, G-Code-Prüfsummen, Bettgrenzen einschließlich Brim/Reinigungsturm, keine Stützen oder Slicer-Druckwarnungen. Farbausgabe bei Z = 0,2/0,4 mm, ausschließlich Weiß im Paneel bei Z = 0,6/0,8 mm.

**Stand: digital geprüfter und geslicter Prototyp, noch kein physisch getestetes Modell.** Passung, Verzug, Lichtdurchlässigkeit, Farbsauberkeit und Dauerbetrieb bleiben durch Probedruck und Betrieb zu prüfen.

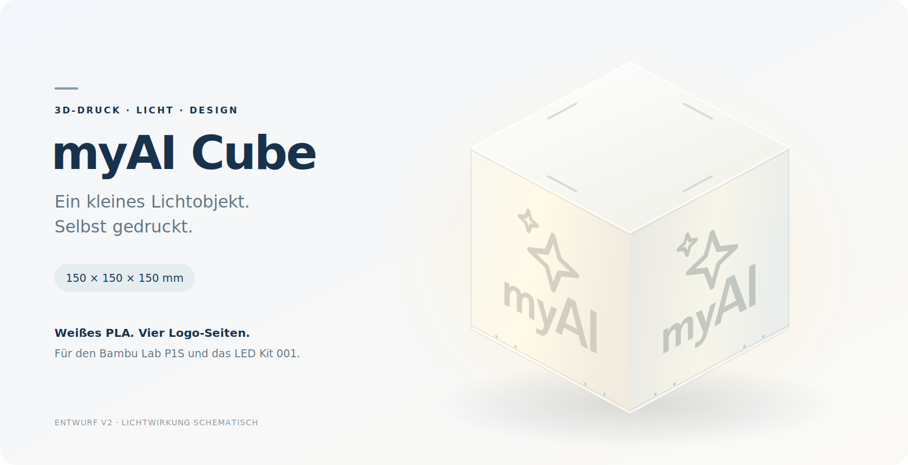
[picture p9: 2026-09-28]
assets/illustrations/myai-cube.png

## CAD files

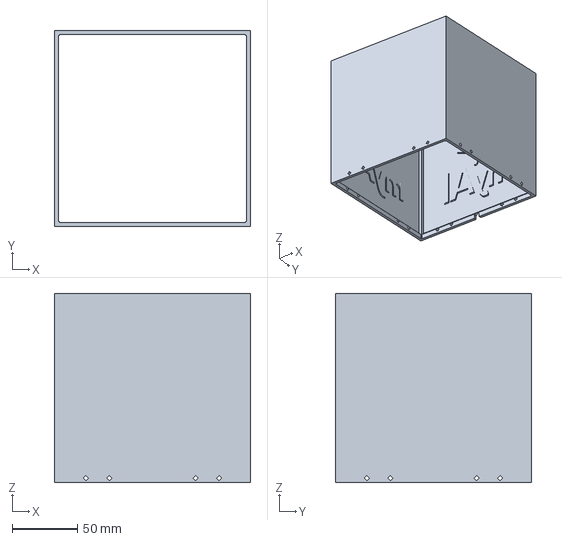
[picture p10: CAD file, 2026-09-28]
output/3mf/02_body_geometry.3mf
150.0 x 150.0 x 145.0 mm

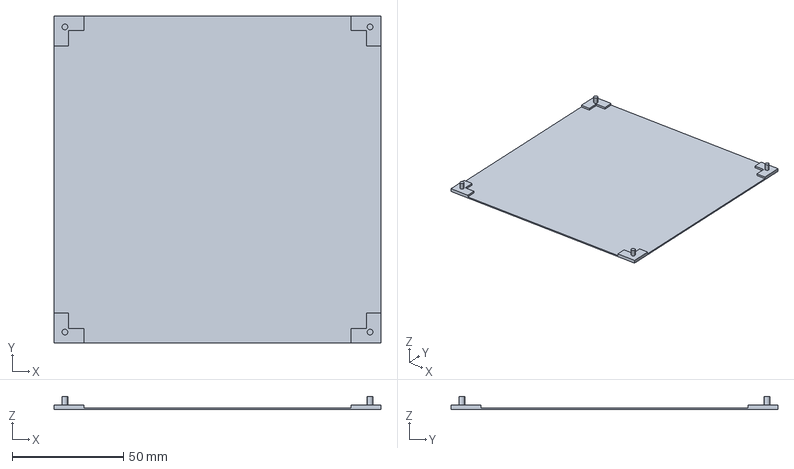
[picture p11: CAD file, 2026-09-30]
output/multicolor_v4/geometry/05_lid.3mf
146.8 x 146.8 x 6.00 mm

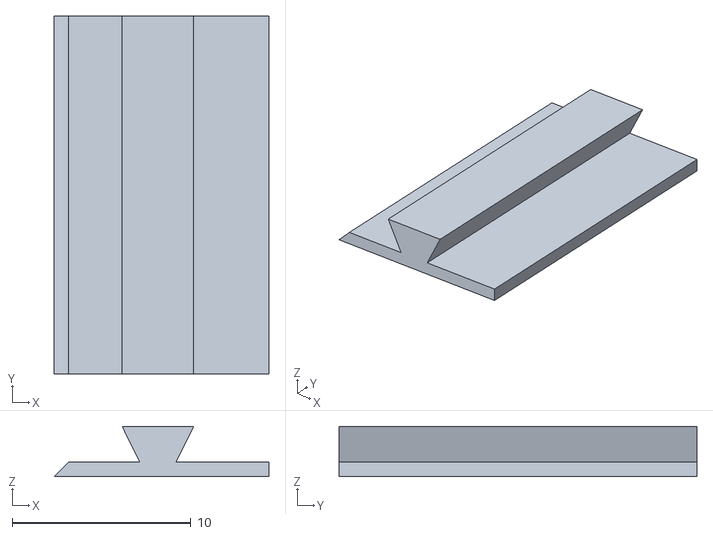
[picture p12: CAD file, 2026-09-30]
output/multicolor_v4/stl/07_fit_panel.stl
12.0 x 20.0 x 2.80

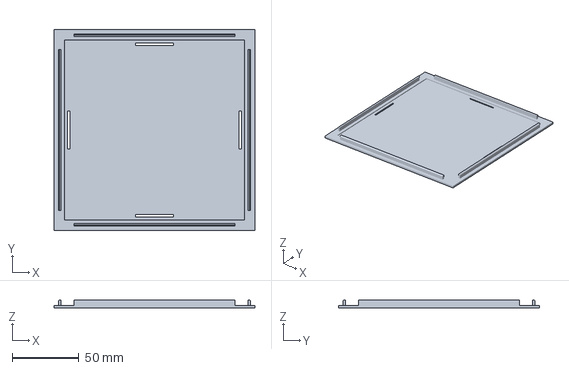
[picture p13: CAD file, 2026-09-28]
output/print/04_lid_P1S.3mf
150.0 x 150.0 x 6.00 mm

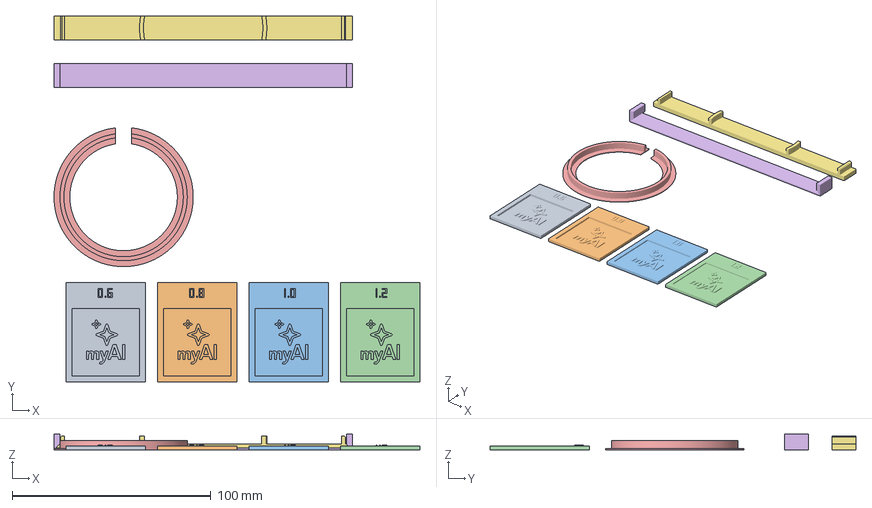
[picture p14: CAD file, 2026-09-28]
output/3mf/01_tests_geometry.3mf
184.0 x 184.0 x 8.00 mm
01a_light_0.6mm
01b_light_0.8mm
01c_light_1.0mm
01d_light_1.2mm
01e_led_fit
01f_joint_socket
01g_joint_rail

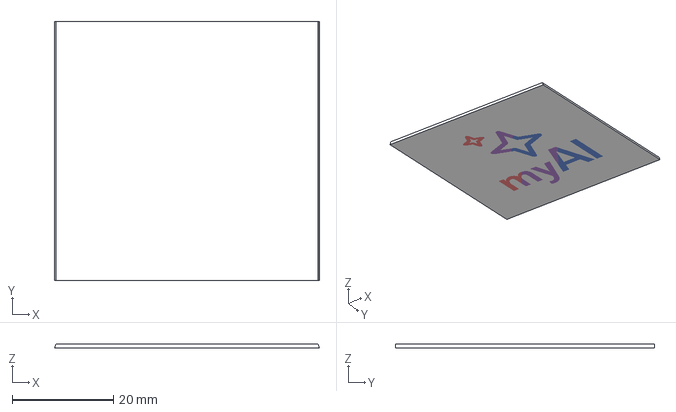
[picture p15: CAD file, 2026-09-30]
output/multicolor_v4/geometry/01_color_test.3mf
52.4 x 51.1 x 0.8 mm

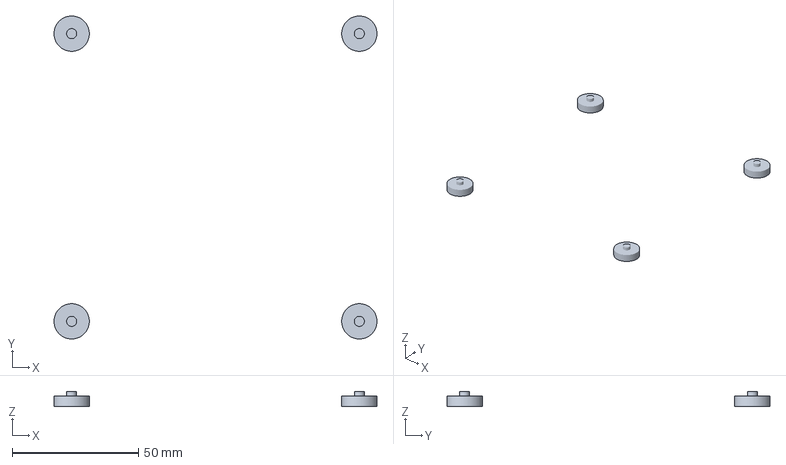
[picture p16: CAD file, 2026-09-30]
output/multicolor_v4/print/06_feet_P1S.3mf
128.0 x 128.0 x 5.80 mm

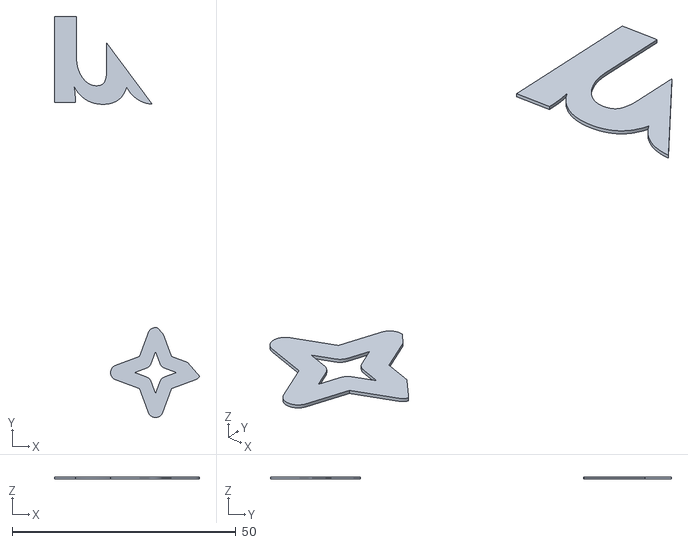
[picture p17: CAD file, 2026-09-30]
output/multicolor_v4/stl/02_panel_4_Rot.stl
32.4 x 89.5 x 0.4

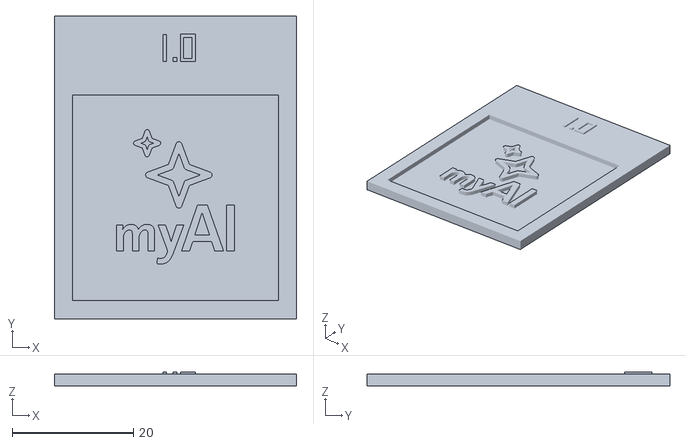
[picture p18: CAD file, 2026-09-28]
output/stl/01c_light_1.0mm.stl
40.0 x 50.0 x 2.38

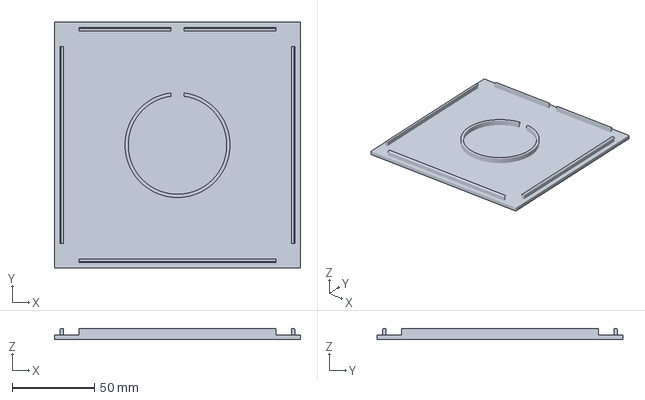
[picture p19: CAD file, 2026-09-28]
output/3mf/03_base_geometry.3mf
150.0 x 150.0 x 7.00 mm

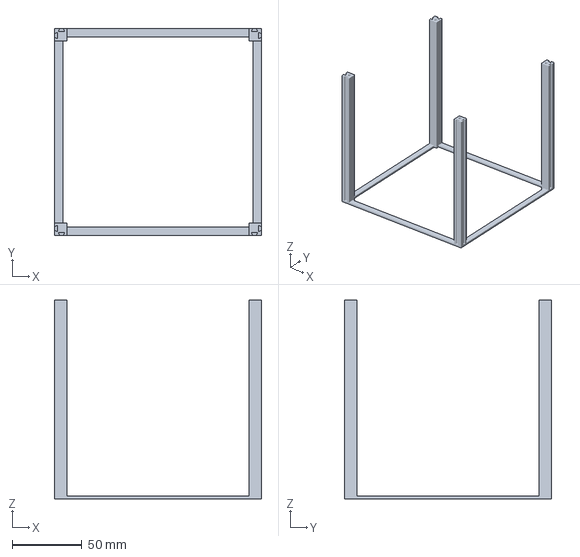
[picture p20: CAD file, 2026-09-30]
output/multicolor_v4/geometry/03_frame.3mf
148.0 x 148.0 x 142.0 mm

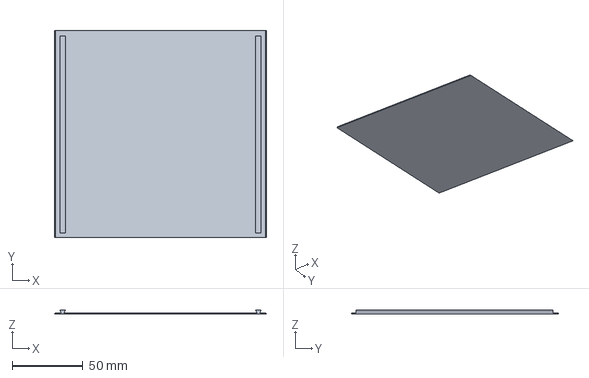
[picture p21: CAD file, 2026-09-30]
output/multicolor_v4/print/02_panel_P1S.3mf
149.6 x 146.0 x 2.80 mm

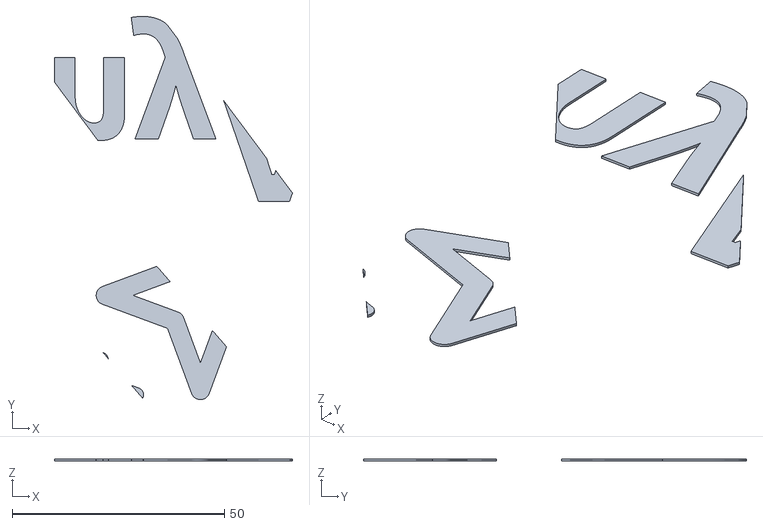
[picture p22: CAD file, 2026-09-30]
output/multicolor_v4/stl/02_panel_3_Violett.stl
56.0 x 90.2 x 0.4

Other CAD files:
output/multicolor_v4/print/05_lid_P1S.3mf
output/stl/02_body.stl
output/print/01_tests_P1S.3mf
output/print/02_body_P1S.3mf
output/stl/01a_light_0.6mm.stl
output/3mf/04_lid_geometry.3mf
output/multicolor_v3/geometry/01_color_test.3mf
output/multicolor_v3/geometry/02_panel.3mf
output/multicolor_v3/geometry/03_frame.3mf
output/multicolor_v3/geometry/04_base.3mf
output/multicolor_v3/geometry/05_lid.3mf
output/multicolor_v3/geometry/06_feet.3mf
output/multicolor_v3/print/01_color_test_P1S.3mf
output/multicolor_v3/print/02_panel_P1S.3mf
output/multicolor_v3/print/03_frame_P1S.3mf
output/multicolor_v3/print/04_base_P1S.3mf
output/multicolor_v3/print/05_lid_P1S.3mf
output/multicolor_v3/print/06_feet_P1S.3mf
output/multicolor_v3/stl/02_panel_1_Weiss.stl
output/multicolor_v3/stl/02_panel_2_Blau.stl
output/multicolor_v3/stl/02_panel_3_Violett.stl
output/multicolor_v3/stl/02_panel_4_Rot.stl
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

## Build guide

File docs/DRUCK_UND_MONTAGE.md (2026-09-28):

# Drucken und zusammenbauen

## 1. Testplatte

Die vier beschrifteten Lichtproben haben freie Flächen mit **0,6 / 0,8 / 1,0 / 1,2 mm** Materialstärke. Der Rahmen ist dicker; das kleine Logo trägt jeweils weitere 0,8 mm auf.

- Nach dem Abkühlen ablösen und den Brim entfernen. Die dünnen Flächen nicht vom warmen Bett ziehen.
- Jede Probe mit demselben LED-Kit, Abstand und Umgebungslicht beurteilen. Helligkeit, sichtbare LED-Hotspots und Logokontrast vergleichen.
- Die Proben liegen beim Druck flach. Die großen Körperwände werden aufrecht gedruckt; deshalb ist dies eine Vorauswahl, keine exakte optische Kalibrierung. Der Hauptentwurf verwendet zunächst **0,8 mm**.
- Das LED-Modul ohne Kraft in den offenen Passring setzen. Dieser hat dieselben 60,0 mm Innendurchmesser wie die Bodenaufnahme. Auch den Kabelausgang prüfen. Das Modul soll hineinpassen, ohne gequetscht zu werden; die endgültige Befestigung erfolgt mit Klebeband.
- Die beiden langen Steckproben prüfen: das U-förmige Gegenstück nach dem Druck umdrehen und auf den Streifen mit den Führungen setzen. Es soll leicht aufliegen, ohne die Wände auseinanderzudrücken. Die Form erprobt gegenüberliegende Führungen mit 0,35 mm Spiel pro Seite.

Wenn Wandstärke oder Passung geändert werden müssen, `cad/parameters.json` anpassen, Geometrie neu erzeugen und neu slicen. Die bestehenden Druckprojekte übernehmen Änderungen nicht automatisch. Noch keine volle Lampe drucken, wenn der Passring nicht zum vorhandenen LED-Kit passt.

## 2. Hauptteile drucken

Alle drei Projekte sind bereits ausgerichtet:

- **Körper:** aufrecht, die unten offene Kabelkerbe auf dem Bett. Nicht auf eine Seitenfläche legen, kein Vasenmodus.
- **Boden:** flache Außenseite auf dem Bett, LED-Ring und Führungen nach oben.
- **Deckel:** flache Außenseite auf dem Bett, Führungen nach oben. Bei der Montage wird er umgedreht.

Die Projekte sind für eine strukturierte PEI-Platte eingerichtet. Weißes PLA mit einem passenden Filamentprofil verwenden. 0,20 mm Schichthöhe, Arachne und die vorbereitete Orientierung beibehalten. 100 % Füllung verhindert ein sichtbares Infill-Raster in den Leuchtflächen und Logos. Die 45°-Übergänge und nach innen geneigten Logo-Reliefs sind ohne Stützen ausgelegt.

Das Bett vor dem Druck reinigen. Brim erst nach dem Abkühlen entfernen, besonders am unteren Körperrand. Die Lüftungs- und Kabelöffnungen von losen Fäden befreien. Keine Logo-Flächen durchschneiden: Die Innenflächen der Buchstaben und Sterne sind Teil der durchgehenden Wand.

## 3. Montage

Benötigt: die drei Druckteile, LED Lamp Kit 001/MH001, dessen doppelseitige Ø-40-mm-Klebescheibe und eine passende 5-V-USB-Stromversorgung. Keine zusätzlichen Schrauben und kein AMS erforderlich.

1. LED-Kit zunächst lose mittig einsetzen und die Kabelrichtung zur Öffnung des Rings ausrichten.
2. Mit der Klebescheibe unter dem LED-Kit am Boden befestigen. Nicht die Leuchtfläche abkleben.
3. Kabel nach hinten zwischen den unterbrochenen Führungsleisten führen.
4. Den Körper über die Führungen auf den Boden setzen. Die unten offene Kabelkerbe muss über dem Kabel liegen; das Kabel darf nicht eingeklemmt werden. USB-Stecker und Schalter bleiben außerhalb.
5. Deckel mit Führungsleisten nach unten einsetzen. An der kleinen rückseitigen Aussparung lässt er sich wieder anheben.
6. Einschalten und Lichtverteilung prüfen. Beim ersten Betrieb nach etwa 30–60 Minuten kontrollieren, dass sich PLA an der LED-Aufnahme nicht verformt. Die Lüftungsöffnungen frei halten.

**Die Steckverbindungen verriegeln nicht.** Zum Versetzen die Lampe am Boden halten. Der Deckel und der Körper bleiben für Wartung abnehmbar.

## Lichtwirkung

Der weiße Würfel leuchtet flächig; die dickeren Logo-Konturen sollen dunkler sichtbar werden. Der genaue Kontrast hängt vom weißen PLA ab. Eine einzelne nach oben gerichtete LED im Boden beleuchtet Seiten und Deckel unterschiedlich; eine gleichmäßige Helligkeit ist noch nicht am physischen Prototyp nachgewiesen. Der Entwurf ist eine diffuse Tischleuchte, ohne zugesicherte Arbeitsplatz-Beleuchtungsstärke.

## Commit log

2026-09-28 Add printable myAI cube lamp design and P1S print projects
    [01_tests_P1S.3mf, 01_tests_geometry.3mf, 01a_light_0.6mm.stl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]
2026-09-28 Add four-color AMS cube lamp prototype with integrated logo panels
    [01_color_test.3mf, 01_color_test_P1S.3mf, 02_panel.3mf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]
2026-09-28 Conceal AMS cube ventilation beneath base and lid edge
    [03_frame.3mf, 03_frame.stl, 03_frame_P1S.3mf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]
2026-09-30 Apply red violet blue bands to both logo stars and wordmark
    [01_color_test.3mf, 01_color_test_P1S.3mf, 02_panel.3mf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]
2026-09-30 Create v4 cube with flush full-face panels and internal sliding guides
    [01_color_test.3mf, 01_color_test_P1S.3mf, 02_panel.3mf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]
2026-10-17 Übernehme Probedruck-Ergebnisse und 0,6-mm-Leuchtflächen für v4.1
2026-10-17 Ergänze AMS-Lichtvergleich für 0,2 und 0,4 mm Farbeinlagen
2026-10-17 Add full-size AMS raster print test with 0.2 mm color layer
2026-10-17 Rebuild raster from original SVG gradients and print color face up
2026-10-17 Prüfe gesamte Rasterfläche und ergänze groben 2-mm-Versuch
2026-10-18 Zeige reine Verlaufsvorschau mit Cyan und 0,8-mm-Farbstreifen
2026-10-18 Erstelle P1S-Testkarte mit 0,48-mm-Farbbahnen und dokumentiere Restlücken
2026-10-19 Untersuche feinere Farbbahnen mit gerundeten Enden und dokumentiere Restlücken
2026-10-19 Verfeinere sämtliche Logo-Farbübergänge in der geraden Streifenvorschau
2026-10-19 Vorschau gerader Farbstreifen mit 0,40 mm Mindestbreite
2026-10-19 CMY-Kalibrierkarte als Vorschau mit Filamentempfehlung
2026-10-19 CMY-Testkarte für P1S erstellen und jede Materiallage prüfen
